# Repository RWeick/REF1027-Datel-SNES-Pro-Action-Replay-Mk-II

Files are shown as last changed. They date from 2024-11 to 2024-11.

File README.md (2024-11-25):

# REF1027-Datel-SNES-Pro-Action-Replay-Mk-II
The Kicad files, rom dump, and PAL Jedec for the SNES Pro Action Replay Mk II by Datel

The LZ95F45 GAL was designed for use with both the SNES PAR MkII and the Sega Genesis PAR 2. It is the same chip used in both devices.

PCB Thickness: 1.0 mm

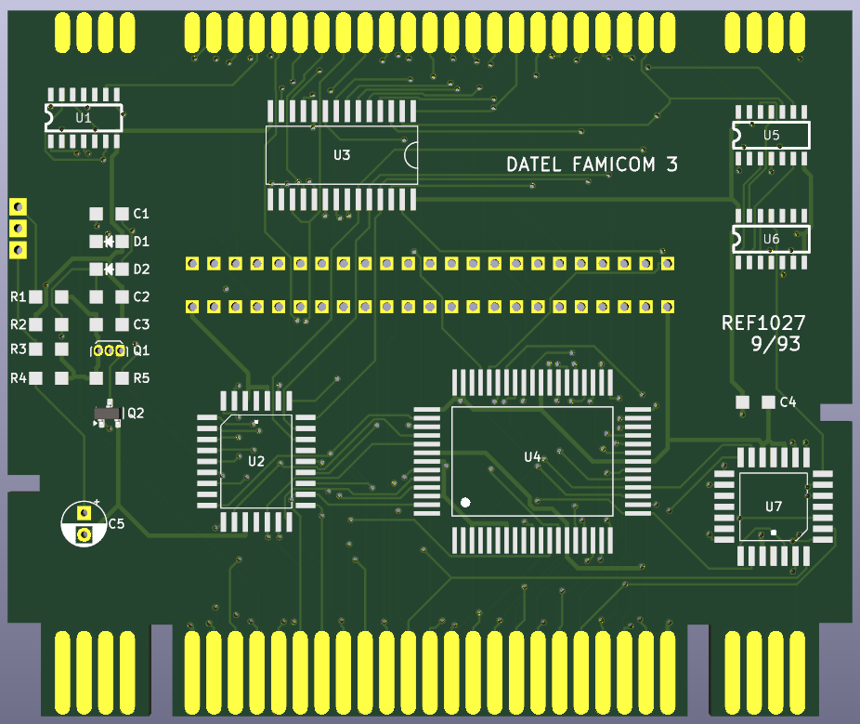
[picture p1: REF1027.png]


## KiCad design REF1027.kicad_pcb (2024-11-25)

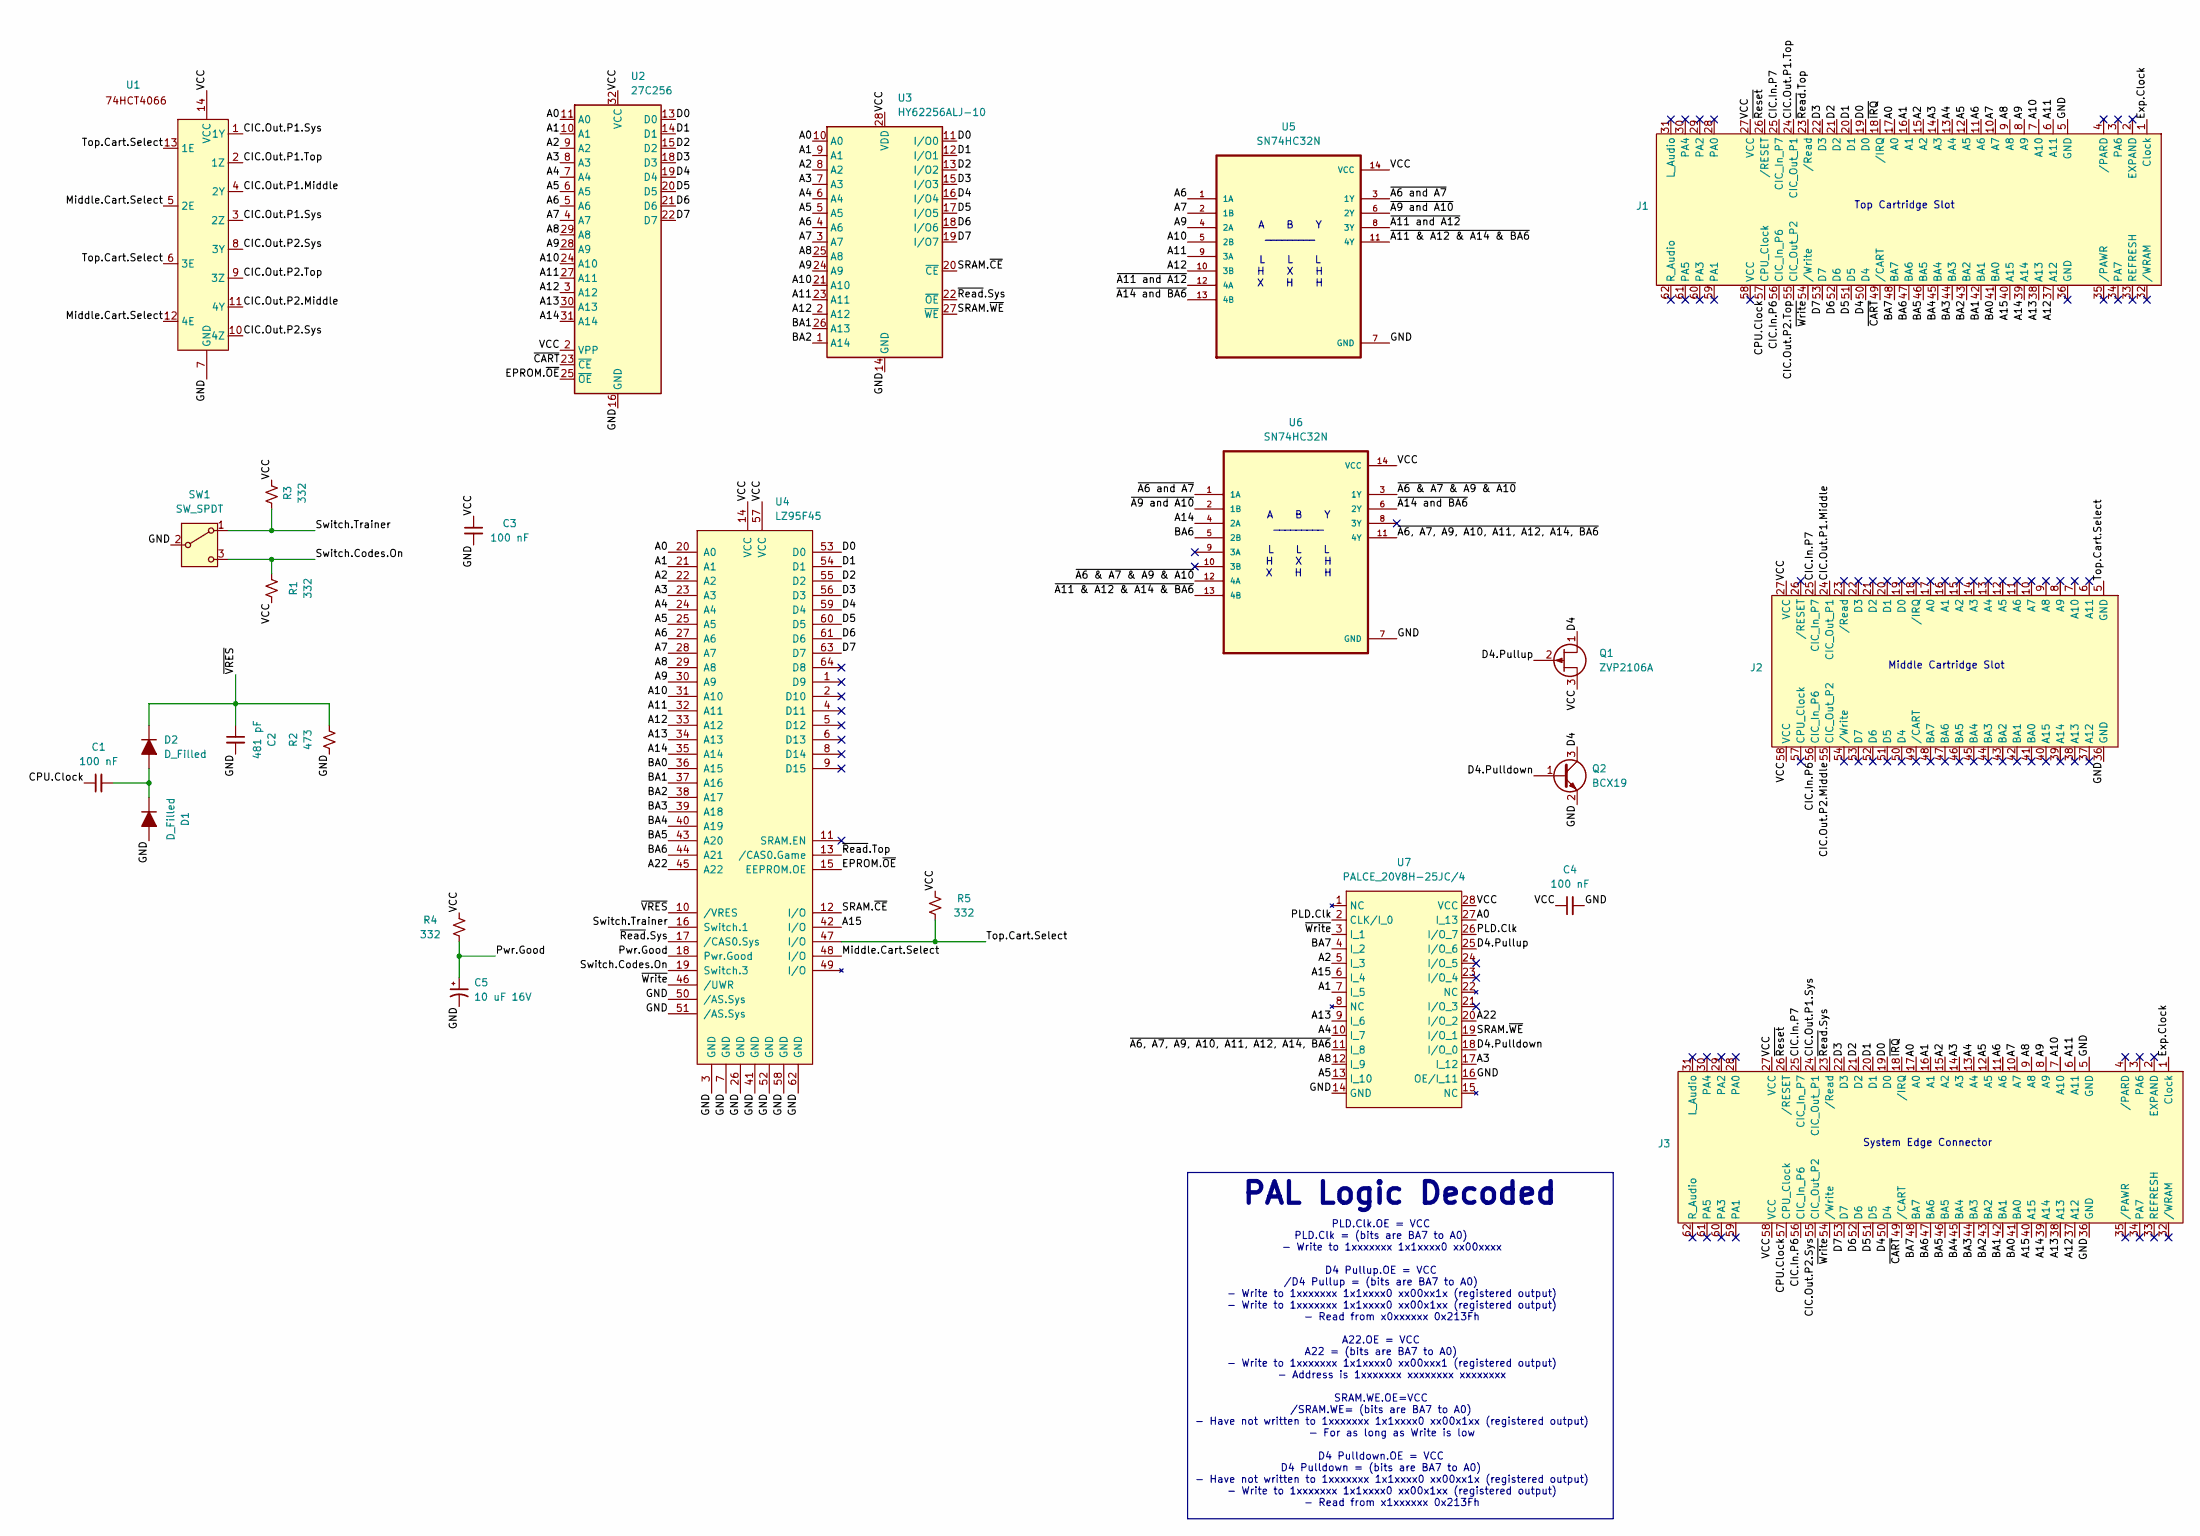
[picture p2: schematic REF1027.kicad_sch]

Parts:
C1, C3, C4: 100 nF; Capacitor
C2: 481 pF; Capacitor
C5: 10 uF 16V; CP_Radial_D5.0mm_P2.50mm
D1, D2: D_Filled; Diode
J1: Top Edge Connector
J2: Middle Cartridge Slot
J3: Bottom Edge Connector
Q1: ZVP2106A; TO-92Flat
Q2: BCX19; SOT-23
R1, R3, R4, R5: 332; Resistor
R2: 473; Resistor
SW1: SW_SPDT; Switch
U1: SOIC-14
U2: 27C256
U3: HY62256ALJ-10; HY62256ALJ
U4: LZ95F45
U5, U6: SN74HC32N; SOIC-14
U7: PALCE_20V8H-25JC/4; PALCE20V8H

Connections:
/A0: J1.17 (A0), J3.17 (A0), U2.11 (A0), U3.10 (A0), U4.20 (A0), U7.27 (I_13)
/A1: J1.16 (A1), J3.16 (A1), U2.10 (A1), U3.9 (A1), U4.21 (A1), U7.7 (I_5)
/A2: J1.15 (A2), J3.15 (A2), U2.9 (A2), U3.8 (A2), U4.22 (A2), U7.5 (I_3)
/A3: J1.14 (A3), J3.14 (A3), U2.8 (A3), U3.7 (A3), U4.23 (A3), U7.17 (I_12)
/A4: J1.13 (A4), J3.13 (A4), U2.7 (A4), U3.6 (A4), U4.24 (A4), U7.10 (I_7)
/A5: J1.12 (A5), J3.12 (A5), U2.6 (A5), U3.5 (A5), U4.25 (A5), U7.13 (I_10)
/A6: J1.11 (A6), J3.11 (A6), U2.5 (A6), U3.4 (A6), U4.27 (A6), U5.1 (1A)
/A7: J1.10 (A7), J3.10 (A7), U2.4 (A7), U3.3 (A7), U4.28 (A7), U5.2 (1B)
/A8: J1.9 (A8), J3.9 (A8), U2.29 (A8), U3.25 (A8), U4.29 (A8), U7.12 (I_9)
/A9: J1.8 (A9), J3.8 (A9), U2.28 (A9), U3.24 (A9), U4.30 (A9), U5.4 (2A)
/A10: J1.7 (A10), J3.7 (A10), U2.24 (A10), U3.21 (A10), U4.31 (A10), U5.5 (2B)
/A11: J1.6 (A11), J3.6 (A11), U2.27 (A11), U3.23 (A11), U4.32 (A11), U5.9 (3A)
/A12: J1.37 (A12), J3.37 (A12), U2.3 (A12), U3.2 (A12), U4.33 (A12), U5.10 (3B)
/A13: J1.38 (A13), J3.38 (A13), U2.30 (A13), U4.34 (A13), U7.9 (I_6)
/A14: J1.39 (A14), J3.39 (A14), U2.31 (A14), U4.35 (A14), U6.4 (2A)
/A15: J1.40 (A15), J3.40 (A15), U4.42 (I/O), U7.6 (I_4)
/A22: U4.45 (A22), U7.20 (I/O_2)
/BA0: J1.41 (BA0), J3.41 (BA0), U4.36 (A15)
/BA1: J1.42 (BA1), J3.42 (BA1), U3.26 (A13), U4.37 (A16)
/BA2: J1.43 (BA2), J3.43 (BA2), U3.1 (A14), U4.38 (A17)
/BA3: J1.44 (BA3), J3.44 (BA3), U4.39 (A18)
/BA4: J1.45 (BA4), J3.45 (BA4), U4.40 (A19)
/BA5: J1.46 (BA5), J3.46 (BA5), U4.43 (A20)
/BA6: J1.47 (BA6), J3.47 (BA6), U4.44 (A21), U6.5 (2B)
/BA7: J1.48 (BA7), J3.48 (BA7), U7.4 (I_2)
/CIC.In.P6: J1.56 (CIC_In_P6), J2.56 (CIC_In_P6), J3.56 (CIC_In_P6)
/CIC.In.P7: J1.25 (CIC_In_P7), J2.25 (CIC_In_P7), J3.25 (CIC_In_P7)
/CIC.Out.P1.Middle: J2.24 (CIC_Out_P1), U1.4 (2Y)
/CIC.Out.P1.Sys: J3.24 (CIC_Out_P1), U1.1 (1Y), U1.3 (2Z)
/CIC.Out.P1.Top: J1.24 (CIC_Out_P1), U1.2 (1Z)
/CIC.Out.P2.Middle: J2.55 (CIC_Out_P2), U1.11 (4Y)
/CIC.Out.P2.Sys: J3.55 (CIC_Out_P2), U1.8 (3Y), U1.10 (4Z)
/CIC.Out.P2.Top: J1.55 (CIC_Out_P2), U1.9 (3Z)
/CPU.Clock: C1.1, J1.57 (CPU_Clock), J3.57 (CPU_Clock)
/D0: J1.19 (D0), J3.19 (D0), U2.13 (D0), U3.11 (I/O0), U4.53 (D0)
/D1: J1.20 (D1), J3.20 (D1), U2.14 (D1), U3.12 (I/O1), U4.54 (D1)
/D2: J1.21 (D2), J3.21 (D2), U2.15 (D2), U3.13 (I/O2), U4.55 (D2)
/D3: J1.22 (D3), J3.22 (D3), U2.18 (D3), U3.15 (I/O3), U4.56 (D3)
/D4: J1.50 (D4), J3.50 (D4), Q1.1 (D), Q2.3 (C), U2.19 (D4), U3.16 (I/O4), U4.59 (D4)
/D4.Pulldown: Q2.1 (B), U7.18 (I/O_0)
/D4.Pullup: Q1.2 (G), U7.25 (I/O_6)
/D5: J1.51 (D5), J3.51 (D5), U2.20 (D5), U3.17 (I/O5), U4.60 (D5)
/D6: J1.52 (D6), J3.52 (D6), U2.21 (D6), U3.18 (I/O6), U4.61 (D6)
/D7: J1.53 (D7), J3.53 (D7), U2.22 (D7), U3.19 (I/O7), U4.63 (D7)
/EPROM.~OE: U2.25 (~OE), U4.15 (EEPROM.OE)
/Exp.Clock: J1.1 (Clock), J3.1 (Clock)
/GND: C2.2, C3.2, C4.2, C5.2, D1.2 (A), J1.5 (GND), J2.36 (GND), J3.5 (GND), J3.36 (GND), Q2.2 (E), R2.1, SW1.2 (B), U1.7 (GND), U2.16 (GND), U3.14 (GND), U4.3 (GND), U4.7 (GND), U4.26 (GND), U4.41 (GND), U4.50 (/AS.Sys), U4.51 (/AS.Sys), U4.52 (GND), U4.58 (GND), U4.62 (GND), U5.7 (GND), U6.7 (GND), U7.14 (GND), U7.16 (OE/I_11)
/Middle.Cart.Select: U1.5 (2E), U1.12 (4E), U4.48 (I/O)
/PLD.Clk: U7.2 (CLK/I_0), U7.26 (I/O_7)
/Pwr.Good: C5.1, R4.1, U4.18 (Pwr.Good)
/SRAM.~CE: U3.20 (~CE), U4.12 (I/O)
/SRAM.~WE: U3.27 (~WE), U7.19 (I/O_1)
/Switch.Codes.On: R1.1, SW1.3 (C), U4.19 (Switch.3)
/Switch.Trainer: R3.1, SW1.1 (A), U4.16 (Switch.1)
/Top.Cart.Select: J2.5 (GND), R5.2, U1.6 (3E), U1.13 (1E), U4.47 (I/O)
/VCC: C3.1, C4.1, J1.27 (VCC), J2.27 (VCC), J2.58 (VCC), J3.27 (VCC), J3.58 (VCC), Q1.3 (S), R1.2, R3.2, R4.2, R5.1, U1.14 (VCC), U2.2 (VPP), U2.32 (VCC), U3.28 (VDD), U4.14 (VCC), U4.57 (VCC), U5.14 (VCC), U6.14 (VCC), U7.28 (VCC)
/~A6 & A7 & A9 & A10: U6.3 (1Y), U6.12 (4A)
/~A6 and A7: U5.3 (1Y), U6.1 (1A)
/~A6, A7, A9, A10, A11, A12, A14, BA6: U6.11 (4Y), U7.11 (I_8)
/~A9 and A10: U5.6 (2Y), U6.2 (1B)
/~A11 & A12 & A14 & BA6: U5.11 (4Y), U6.13 (4B)
/~A11 and A12: U5.8 (3Y), U5.12 (4A)
/~A14 and BA6: U5.13 (4B), U6.6 (2Y)
/~CART: J1.49 (/CART), J3.49 (/CART), U2.23 (~CE)
/~IRQ: J1.18 (/IRQ), J3.18 (/IRQ)
/~Read.Sys: J3.23 (/Read), U3.22 (~OE), U4.17 (/CAS0.Sys)
/~Read.Top: J1.23 (/Read), U4.13 (/CAS0.Game)
/~Reset: J1.26 (/RESET), J3.26 (/RESET)
/~VRES: C2.1, D2.1 (K), R2.2, U4.10 (/VRES)
/~Write: J1.54 (/Write), J3.54 (/Write), U4.46 (/UWR), U7.3 (I_1)
unnamed: C1.2, D1.1 (K), D2.2 (A)

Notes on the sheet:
Top Cartridge Slot
A B Y _________ L L L H X H X H H
System Edge Connector
Middle Cartridge Slot
PAL Logic Decoded
PLD.Clk.OE = VCC PLD.Clk = (bits are BA7 to A0) - Write to 1xxxxxxx 1x1xxxx0 xx00xxxx D4 Pullup.OE = VCC /D4 Pullup = (bits are BA7 to A0) - Write to 1xxxxxxx 1x1xxxx0 xx00xx1x (registered output) - Write to 1xxxxxxx 1x1xxxx0 xx00x1xx (registered output) - Read from x0xxxxxx 0x213Fh A22.OE = VCC A2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

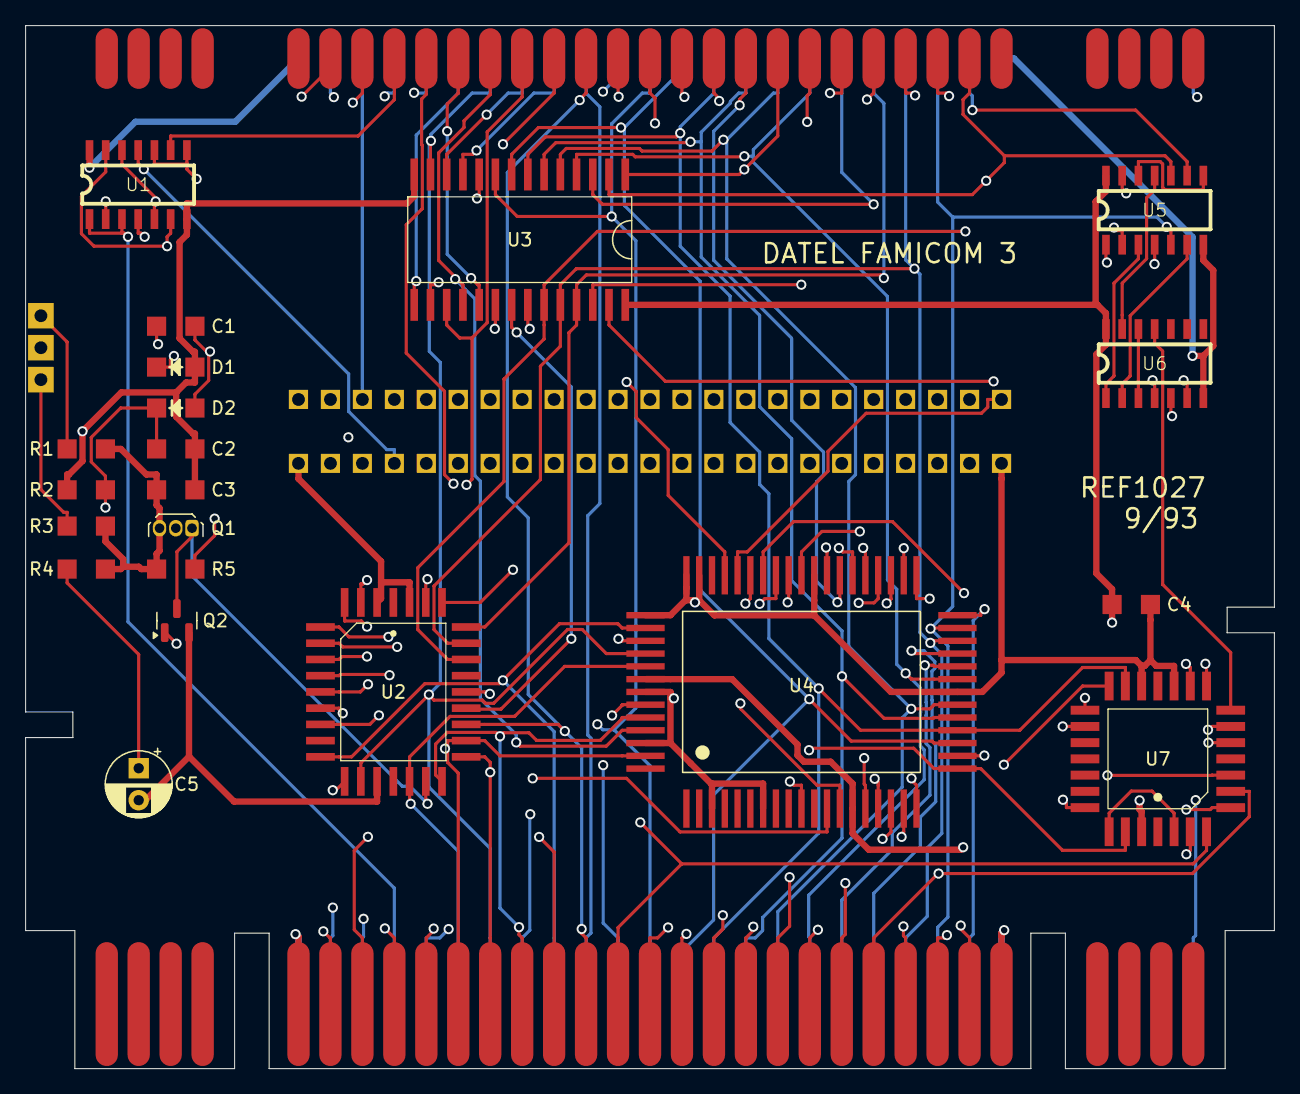
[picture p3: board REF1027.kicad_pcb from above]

Board: 4 copper layers, 97.7 x 81.6 mm, 25 parts (0 on the bottom side), 71 nets.
